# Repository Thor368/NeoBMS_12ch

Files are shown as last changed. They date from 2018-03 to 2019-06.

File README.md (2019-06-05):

# NeoBMS_12ch
Flexible NeoBMS slave board with 12 channels to connect to the battery.

## V1.0
- slave board with internal balancing switches
- 100mA per channel max
- 400mA per slave max
- expansion connector for temp/current measurment board

## V2.0
- slave board with external balancing switches
- 100mA per channel max
- should improve measurement accuracy (no heat in chip)

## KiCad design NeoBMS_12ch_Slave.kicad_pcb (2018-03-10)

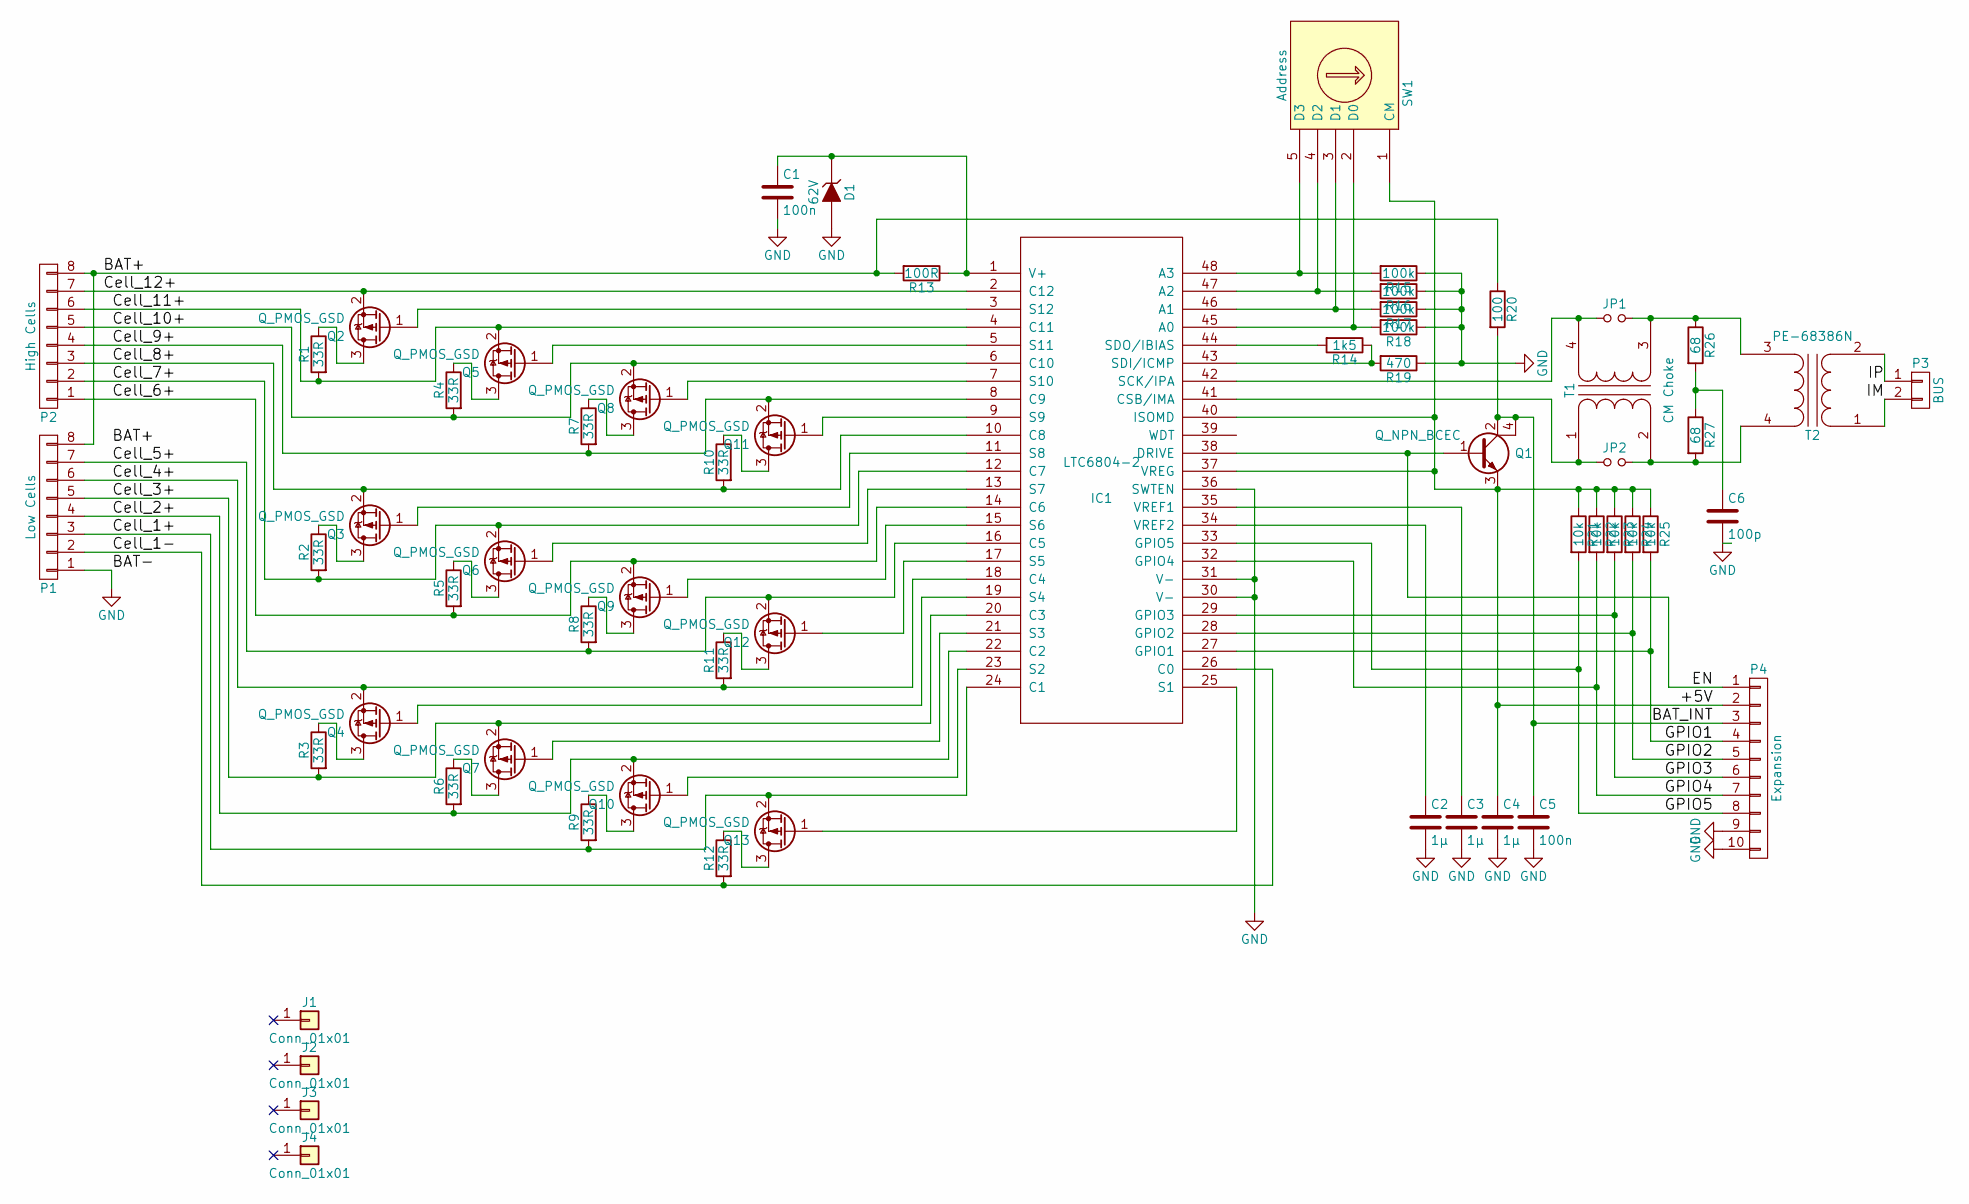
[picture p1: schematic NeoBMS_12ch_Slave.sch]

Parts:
C1, C5: 100n; C_0805
C2, C3, C4: 1µ; C_0805
C6: 100p; C_0805
D1: 62V; MiniMELF_Standard
IC1: LTC6804-2; TSSOP-48_6.1x12.5mm_Pitch0.5mm
J1, J2, J3, J4: Conn_01x01; MountingHole_3.5mm
JP1, JP2: Jumper_NO_Small; Jumper_2
P1: Low Cells; WAGO_micro_8
P2: High Cells; WAGO_micro_8
P3: BUS; WAGO_micro_2
P4: Expansion; pin_array_2x5_lock
Q1: Q_NPN_BCEC; SOT-223
Q2, Q3, Q4, Q5, Q6, Q7, Q8, Q9, Q10, Q11, Q12, Q13: Q_PMOS_GSD; SOT-23
R1, R2, R3, R4, R5, R6, R7, R8, R9, R10, R11, R12: 33R; R_1210
R13: 100R; R_0805
R14: 1k5; R_0805
R15, R16, R17, R18: 100k; R_0805
R19: 470; R_0805
R20: 100; R_0805
R21, R22, R23, R24, R25: 10k; R_0805
R26, R27: 68; R_0805
SW1: Address; Codingswitch
T1: CM Choke; DLW43S
T2: PE-68386N; PE-68386NL

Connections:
/+5V: C4.1, IC1.37 (VREG), IC1.40 (ISOMD), P4.2, Q1.3 (E), R21.1, R22.1, R23.1, R24.1, R25.1, SW1.1 (CM)
/BAT+: P1.8, P2.8, R13.2, R20.1
/BAT_INT: C5.1, P4.3, Q1.2 (C), Q1.4 (C), R20.2
/Cell_1+: IC1.24 (C1), P1.3, Q13.2 (S), R9.2
/Cell_1-: IC1.26 (C0), P1.2, R12.2
/Cell_2+: IC1.22 (C2), P1.4, Q10.2 (S), R6.2
/Cell_3+: IC1.20 (C3), P1.5, Q7.2 (S), R3.2
/Cell_4+: IC1.18 (C4), P1.6, Q4.2 (S), R11.2
/Cell_5+: IC1.16 (C5), P1.7, Q12.2 (S), R8.2
/Cell_6+: IC1.14 (C6), P2.1, Q9.2 (S), R5.2
/Cell_7+: IC1.12 (C7), P2.2, Q6.2 (S), R2.2
/Cell_8+: IC1.10 (C8), P2.3, Q3.2 (S), R10.2
/Cell_9+: IC1.8 (C9), P2.4, Q11.2 (S), R7.2
/Cell_10+: IC1.6 (C10), P2.5, Q8.2 (S), R4.2
/Cell_11+: IC1.4 (C11), P2.6, Q5.2 (S), R1.2
/Cell_12+: IC1.2 (C12), P2.7, Q2.2 (S)
/EN: IC1.38 (DRIVE), P4.1, Q1.1 (B)
/GPIO1: IC1.27 (GPIO1), P4.4, R25.2
/GPIO2: IC1.28 (GPIO2), P4.5, R24.2
/GPIO3: IC1.29 (GPIO3), P4.6, R23.2
/GPIO4: IC1.32 (GPIO4), P4.7, R22.2
/GPIO5: IC1.33 (GPIO5), P4.8, R21.2
/IM: P3.2, T2.1 (AA)
/IP: P3.1, T2.2 (AB)
GND: C1.2, C2.2, C3.2, C4.2, C5.2, C6.2, D1.2 (A), IC1.30 (V-), IC1.31 (V-), IC1.36 (SWTEN), P1.1, P4.9, P4.10, R15.1, R16.1, R17.1, R18.1, R19.1
unnamed: C1.1, D1.1 (K), IC1.1 (V+), R13.1
unnamed: C2.1, IC1.34 (VREF2)
unnamed: C3.1, IC1.35 (VREF1)
unnamed: C6.1, R26.2, R27.1
unnamed: IC1.3 (S12), Q2.1 (G)
unnamed: IC1.5 (S11), Q5.1 (G)
unnamed: IC1.7 (S10), Q8.1 (G)
unnamed: IC1.9 (S9), Q11.1 (G)
unnamed: IC1.11 (S8), Q3.1 (G)
unnamed: IC1.13 (S7), Q6.1 (G)
unnamed: IC1.15 (S6), Q9.1 (G)
unnamed: IC1.17 (S5), Q12.1 (G)
unnamed: IC1.19 (S4), Q4.1 (G)
unnamed: IC1.21 (S3), Q7.1 (G)
unnamed: IC1.23 (S2), Q10.1 (G)
unnamed: IC1.25 (S1), Q13.1 (G)
unnamed: IC1.41 (CSB/IMA), JP2.1, T1.1 (AA)
unnamed: IC1.42 (SCK/IPA), JP1.1, T1.4 (SB)
unnamed: IC1.43 (SDI/ICMP), R14.1, R19.2
unnamed: IC1.44 (SDO/IBIAS), R14.2
unnamed: IC1.45 (A0), R18.2, SW1.2 (D0)
unnamed: IC1.46 (A1), R17.2, SW1.3 (D1)
unnamed: IC1.47 (A2), R16.2, SW1.4 (D2)
unnamed: IC1.48 (A3), R15.2, SW1.5 (D3)
unnamed: JP1.2, R26.1, T1.3 (SA), T2.3 (SA)
unnamed: JP2.2, R27.2, T1.2 (AB), T2.4 (SB)
unnamed: Q2.3 (D), R1.1
unnamed: Q3.3 (D), R2.1
unnamed: Q4.3 (D), R3.1
unnamed: Q5.3 (D), R4.1
unnamed: Q6.3 (D), R5.1
unnamed: Q7.3 (D), R6.1
unnamed: Q8.3 (D), R7.1
unnamed: Q9.3 (D), R8.1
unnamed: Q10.3 (D), R9.1
unnamed: Q11.3 (D), R10.1
unnamed: Q12.3 (D), R11.1
unnamed: Q13.3 (D), R12.1

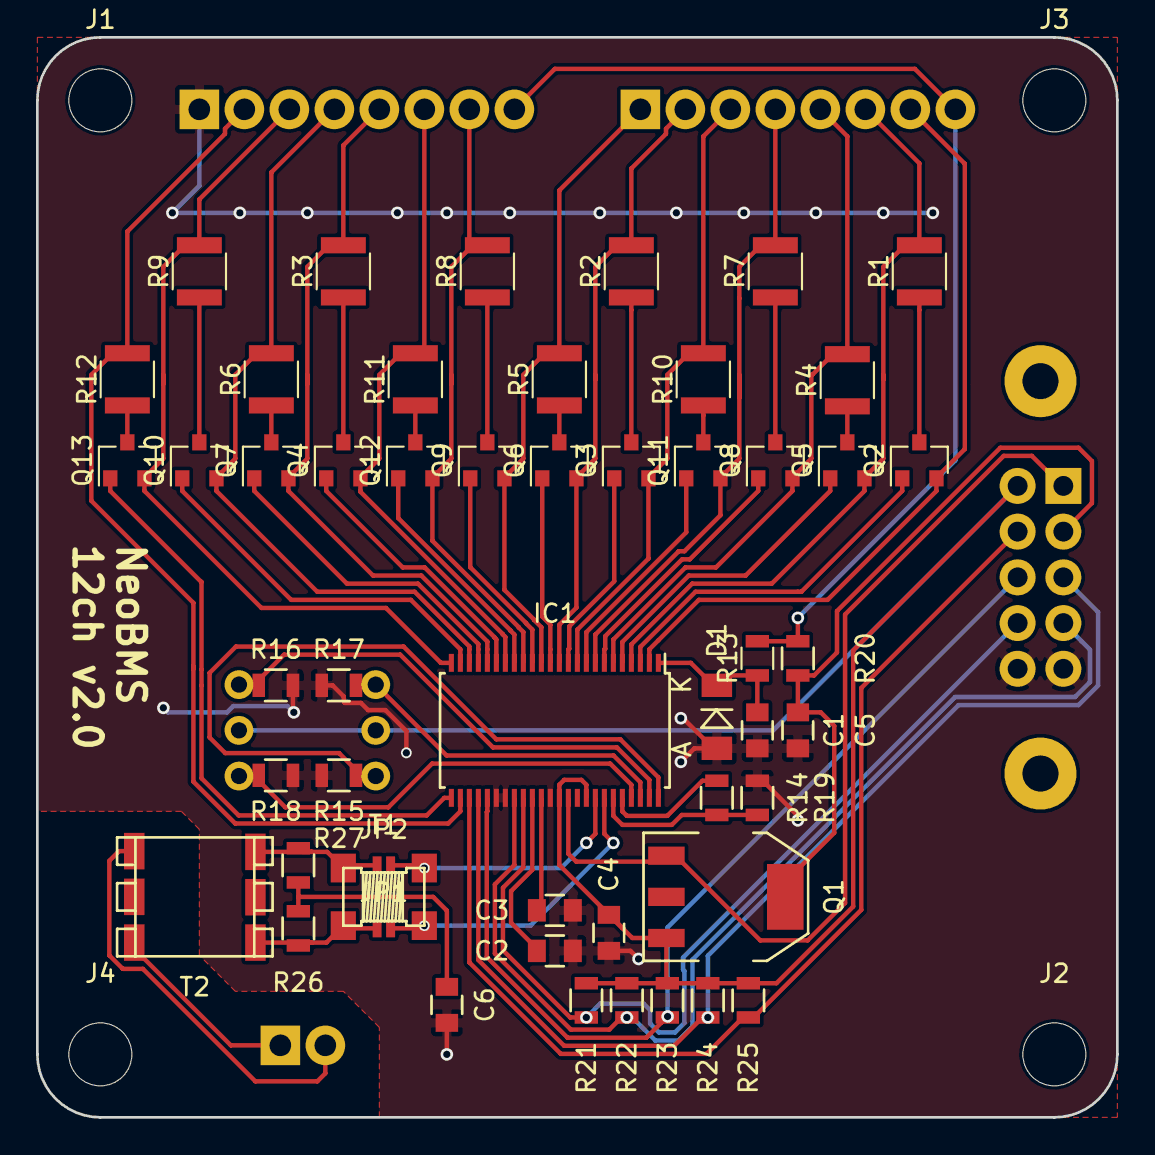
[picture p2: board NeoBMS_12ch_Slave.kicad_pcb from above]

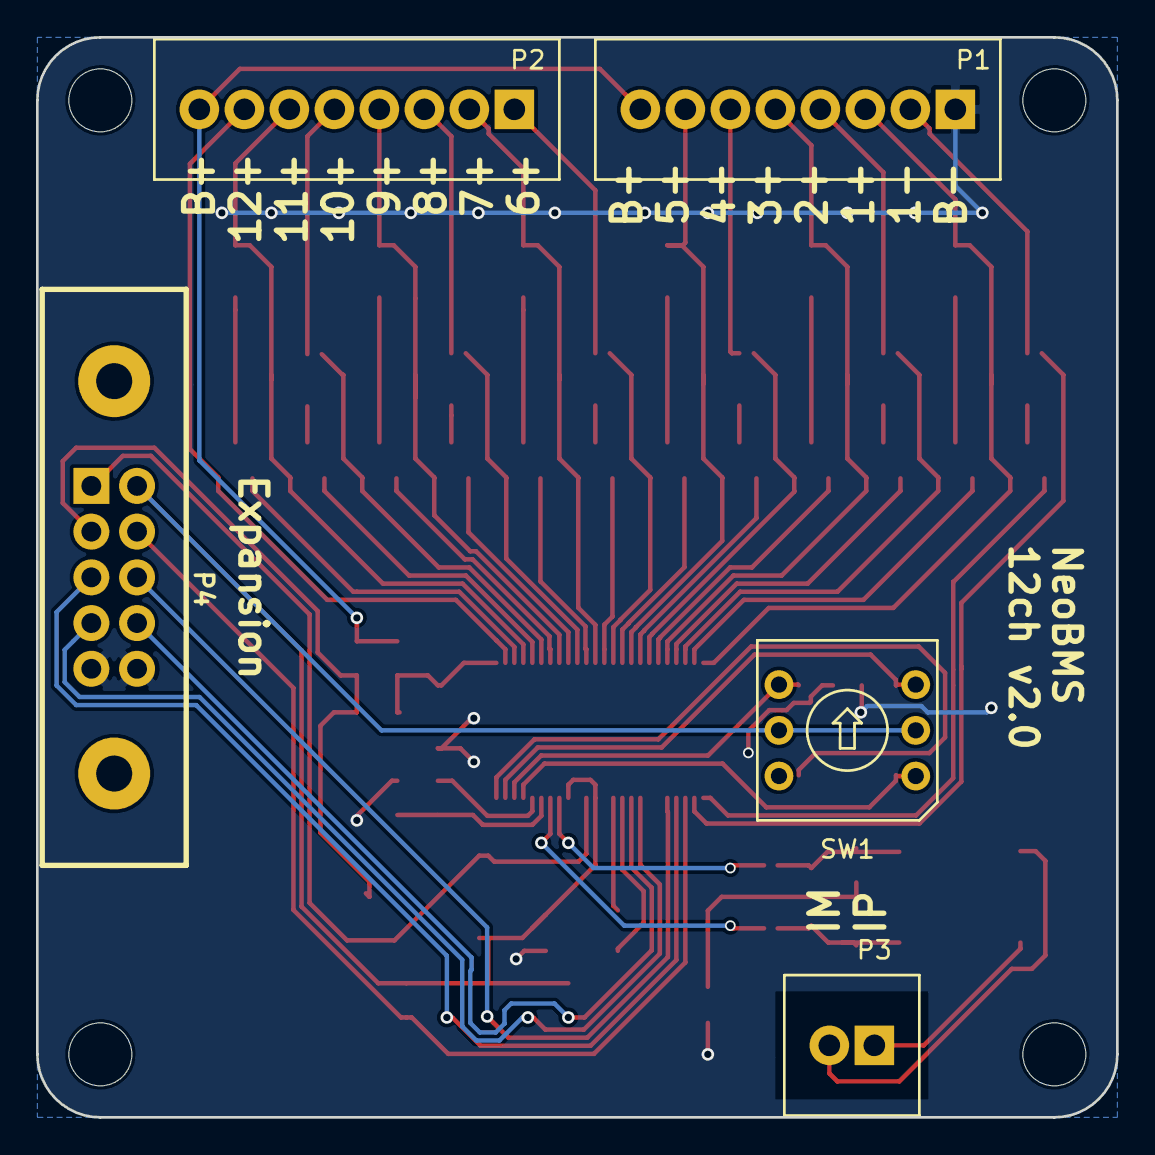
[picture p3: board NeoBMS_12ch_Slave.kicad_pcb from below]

Board: 2 copper layers, 60.0 x 60.0 mm, 61 parts (5 on the bottom side), 63 nets.

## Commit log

2018-03-08 - final version of the internal switched balancing circuit
    [NeoBMS_12ch_Slave.kicad_pcb, NeoBMS_12ch_Slave.sch]
2018-03-08 - integrated balancer and filter resistors into one - changed filter/balancer resistors to 1206 - changed BIAS network to 1k5 + 470R - relocated BIAS network
    [NeoBMS_12ch_Slave.kicad_pcb, NeoBMS_12ch_Slave.sch]
2018-03-10 - jump to version 2.0 - external balancing switches
    [NeoBMS_12ch_Slave.kicad_pcb, NeoBMS_12ch_Slave.sch]
